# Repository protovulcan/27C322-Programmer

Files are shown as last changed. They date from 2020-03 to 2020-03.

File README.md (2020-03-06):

# ST27C322 EPROM Programmer

Build Rev-1a
  
This schematic is for an EPROM programmer that I put together to allow me to build a switchable Amiga Kickstart.  The plan is to put DiagROM and Kickstarts v1.3, v2.4, and v3.1.1 on a single EPROM. It uses a boost converter to generate the programming voltage _VPP_ so it can be run from USB only. It uses [MCP23017](./docs/MCP23017-datasheet.pdf) IO extenders to generate enough Address and Data lines. The Data lines are driven by the io extender at ```0x20``` while the high data lines are driven by the io extender at ```0x24```.

The current state of this board is alpha. The drill holes for the socket are too small and there are things that need to be properly tested.

The intention with the firmware is to make it handle intel hex via terminal with an ```PASSED``` or:

>
> ERR @ b###########: 0x#### != 0x####
>

# Pinout 

| Arduino | Connected |
|-|-|
| D5 | Address 0 |
| D6 | Address 1 |
| D7 | Address 2 |
| D8 | Address 3 |
| D9 | Address 4 |
| D10 | Programmer Enable - turns on boost converter |
| A0 | INTB on Address io extender |
| A1 | INTA on Address io extender |
| A2 | INTB on Data io extender |
| A3 | INTA on Data io extender |
| A4 | SDA of I2C bus |
| A5 | SDC of I2C bus |
| A6 | RESET of io extender |
| A7 | ENABLE for EEPROM |

# Schematic 

The following schematic was made with KiCAD 5.1.5.  It is currently inadequtely tested.

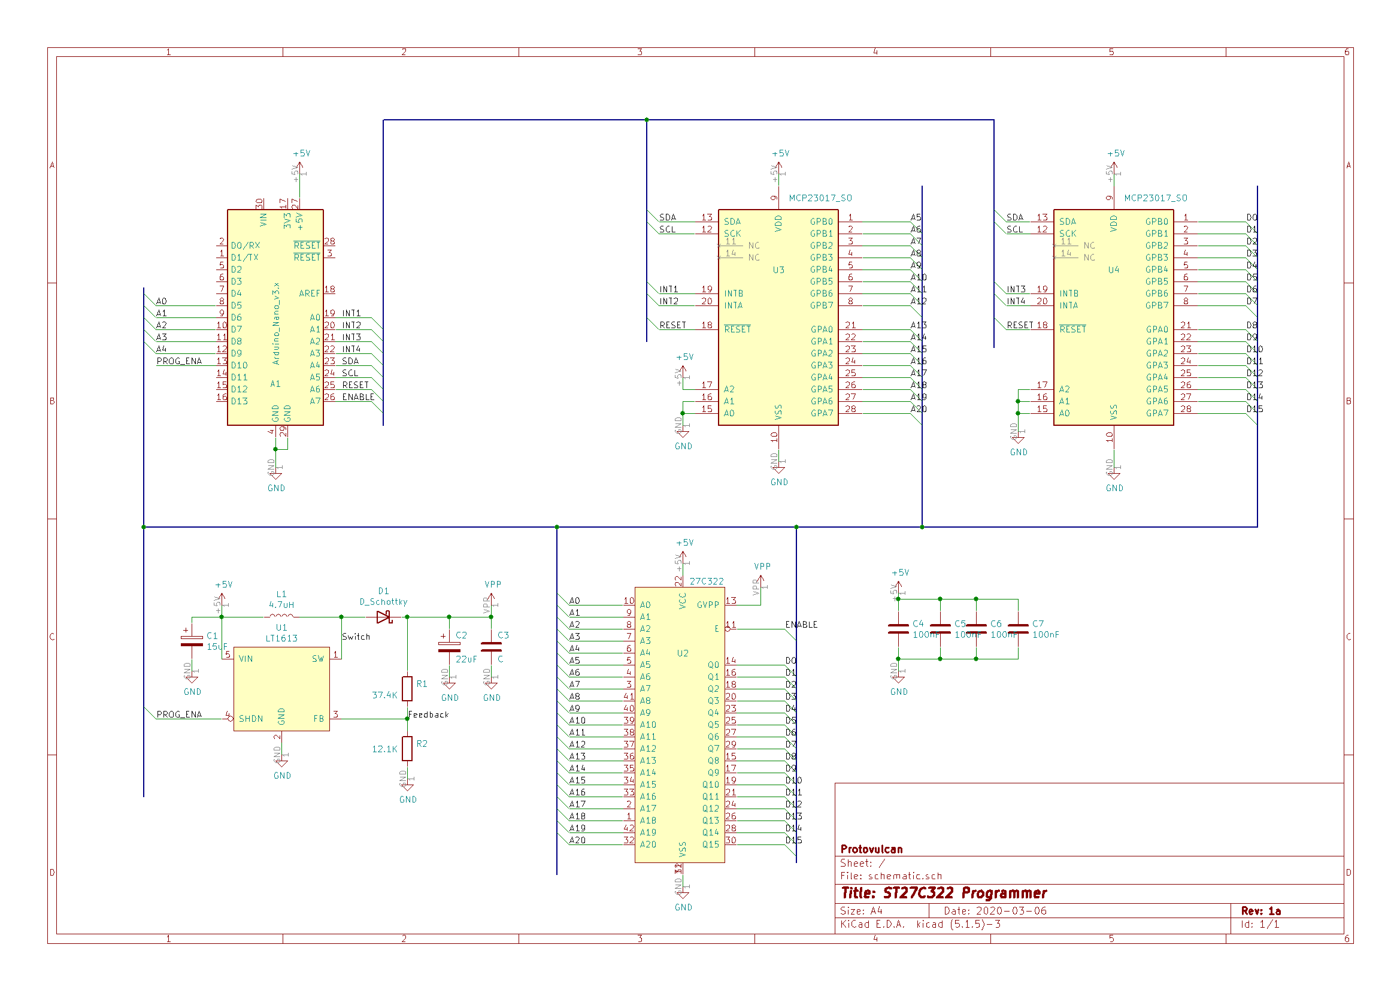
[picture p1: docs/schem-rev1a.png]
Schematic


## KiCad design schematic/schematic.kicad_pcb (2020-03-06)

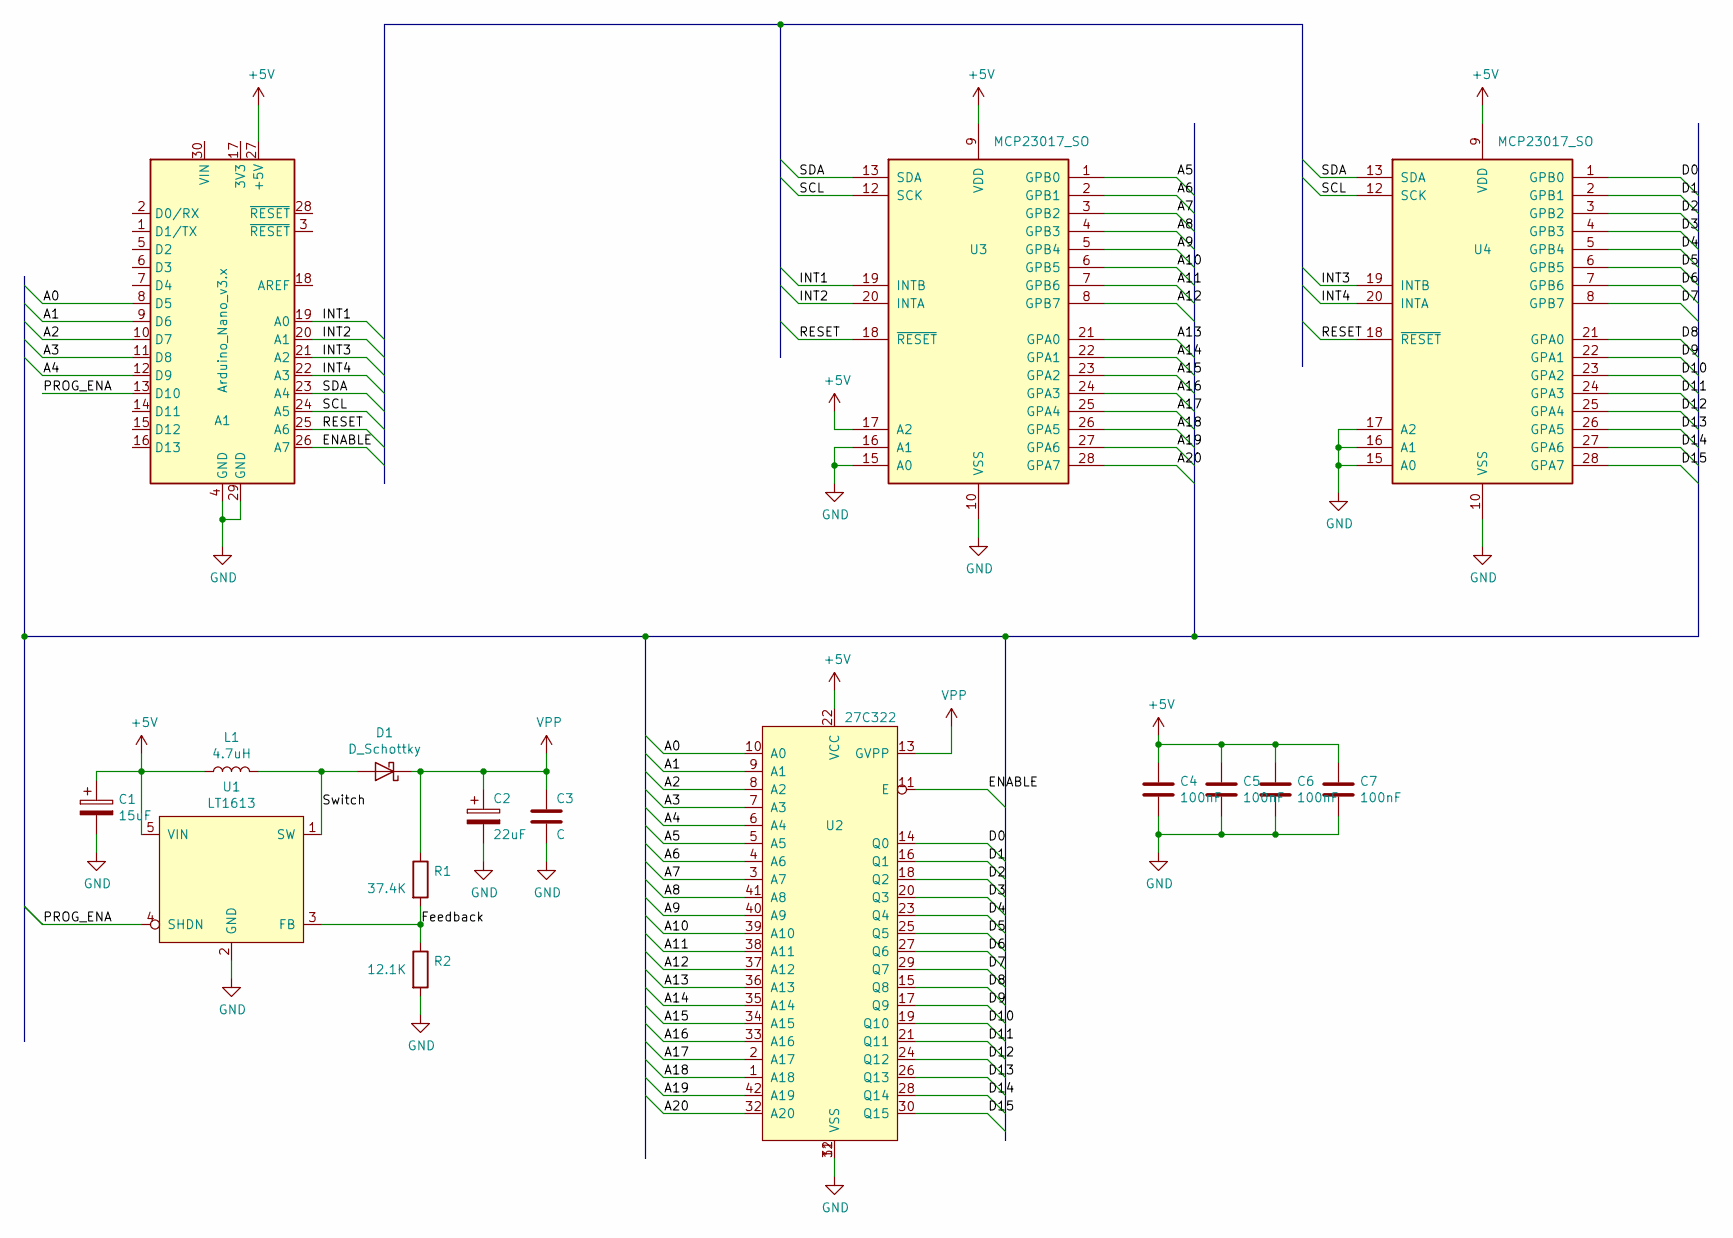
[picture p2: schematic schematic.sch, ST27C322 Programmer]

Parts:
A1: Arduino_Nano_v3.x; Arduino_Nano
C1: 15uF; C_Elec_8x6.2
C2: 22uF; C_Elec_8x6.2
C3: C; C_1210_3225Metric
C4, C5, C6, C7: 100nF; R_1206_3216Metric
D1: D_Schottky; R_1206_3216Metric
L1: 4.7uH; L_10.4x10.4_H4.8
R1: 37.4K; R_1206_3216Metric
R2: 12.1K; R_1206_3216Metric
U1: LT1613; SOT-23-5_HandSoldering
U2: 27C322; DIP-42_W15.24mm_Socket_LongPads
U3, U4: MCP23017_SO; SOIC-28W_7.5x17.9mm_P1.27mm

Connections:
+5V: A1.27 (+5V), C1.1, C4.1, C5.1, C6.1, C7.1, L1.1, U1.5 (VIN), U2.22 (VCC), U3.9 (VDD), U3.17 (A2), U4.9 (VDD)
/A0: A1.8 (D5), U2.10 (A0)
/A1: A1.9 (D6), U2.9 (A1)
/A2: A1.10 (D7), U2.8 (A2)
/A3: A1.11 (D8), U2.7 (A3)
/A4: A1.12 (D9), U2.6 (A4)
/A5: U2.5 (A5), U3.1 (GPB0)
/A6: U2.4 (A6), U3.2 (GPB1)
/A7: U2.3 (A7), U3.3 (GPB2)
/A8: U2.41 (A8), U3.4 (GPB3)
/A9: U2.40 (A9), U3.5 (GPB4)
/A10: U2.39 (A10), U3.6 (GPB5)
/A11: U2.38 (A11), U3.7 (GPB6)
/A12: U2.37 (A12), U3.8 (GPB7)
/A13: U2.36 (A13), U3.21 (GPA0)
/A14: U2.35 (A14), U3.22 (GPA1)
/A15: U2.34 (A15), U3.23 (GPA2)
/A16: U2.33 (A16), U3.24 (GPA3)
/A17: U2.2 (A17), U3.25 (GPA4)
/A18: U2.1 (A18), U3.26 (GPA5)
/A19: U2.42 (A19), U3.27 (GPA6)
/A20: U2.32 (A20), U3.28 (GPA7)
/D0: U2.14 (Q0), U4.1 (GPB0)
/D1: U2.16 (Q1), U4.2 (GPB1)
/D2: U2.18 (Q2), U4.3 (GPB2)
/D3: U2.20 (Q3), U4.4 (GPB3)
/D4: U2.23 (Q4), U4.5 (GPB4)
/D5: U2.25 (Q5), U4.6 (GPB5)
/D6: U2.27 (Q6), U4.7 (GPB6)
/D7: U2.29 (Q7), U4.8 (GPB7)
/D8: U2.15 (Q8), U4.21 (GPA0)
/D9: U2.17 (Q9), U4.22 (GPA1)
/D10: U2.19 (Q10), U4.23 (GPA2)
/D11: U2.21 (Q11), U4.24 (GPA3)
/D12: U2.24 (Q12), U4.25 (GPA4)
/D13: U2.26 (Q13), U4.26 (GPA5)
/D14: U2.28 (Q14), U4.27 (GPA6)
/D15: U2.30 (Q15), U4.28 (GPA7)
/ENABLE: A1.26 (A7), U2.11 (E)
/Feedback: R1.2, R2.1, U1.3 (FB)
/INT1: A1.19 (A0), U3.19 (INTB)
/INT2: A1.20 (A1), U3.20 (INTA)
/INT3: A1.21 (A2), U4.19 (INTB)
/INT4: A1.22 (A3), U4.20 (INTA)
/PROG_ENA: A1.13 (D10), U1.4 (SHDN)
/RESET: A1.25 (A6), U3.18 (~RESET~), U4.18 (~RESET~)
/SCL: A1.24 (A5), U3.12 (SCK), U4.12 (SCK)
/SDA: A1.23 (A4), U3.13 (SDA), U4.13 (SDA)
/Switch: D1.2 (A), L1.2, U1.1 (SW)
GND: A1.4 (GND), A1.29 (GND), C1.2, C2.2, C3.2, C4.2, C5.2, C6.2, C7.2, R2.2, U1.2 (GND), U2.12 (VSS), U2.31 (VSS), U3.10 (VSS), U3.15 (A0), U3.16 (A1), U4.10 (VSS), U4.15 (A0), U4.16 (A1), U4.17 (A2)
VPP: C2.1, C3.1, D1.1 (K), R1.1, U2.13 (GVPP)

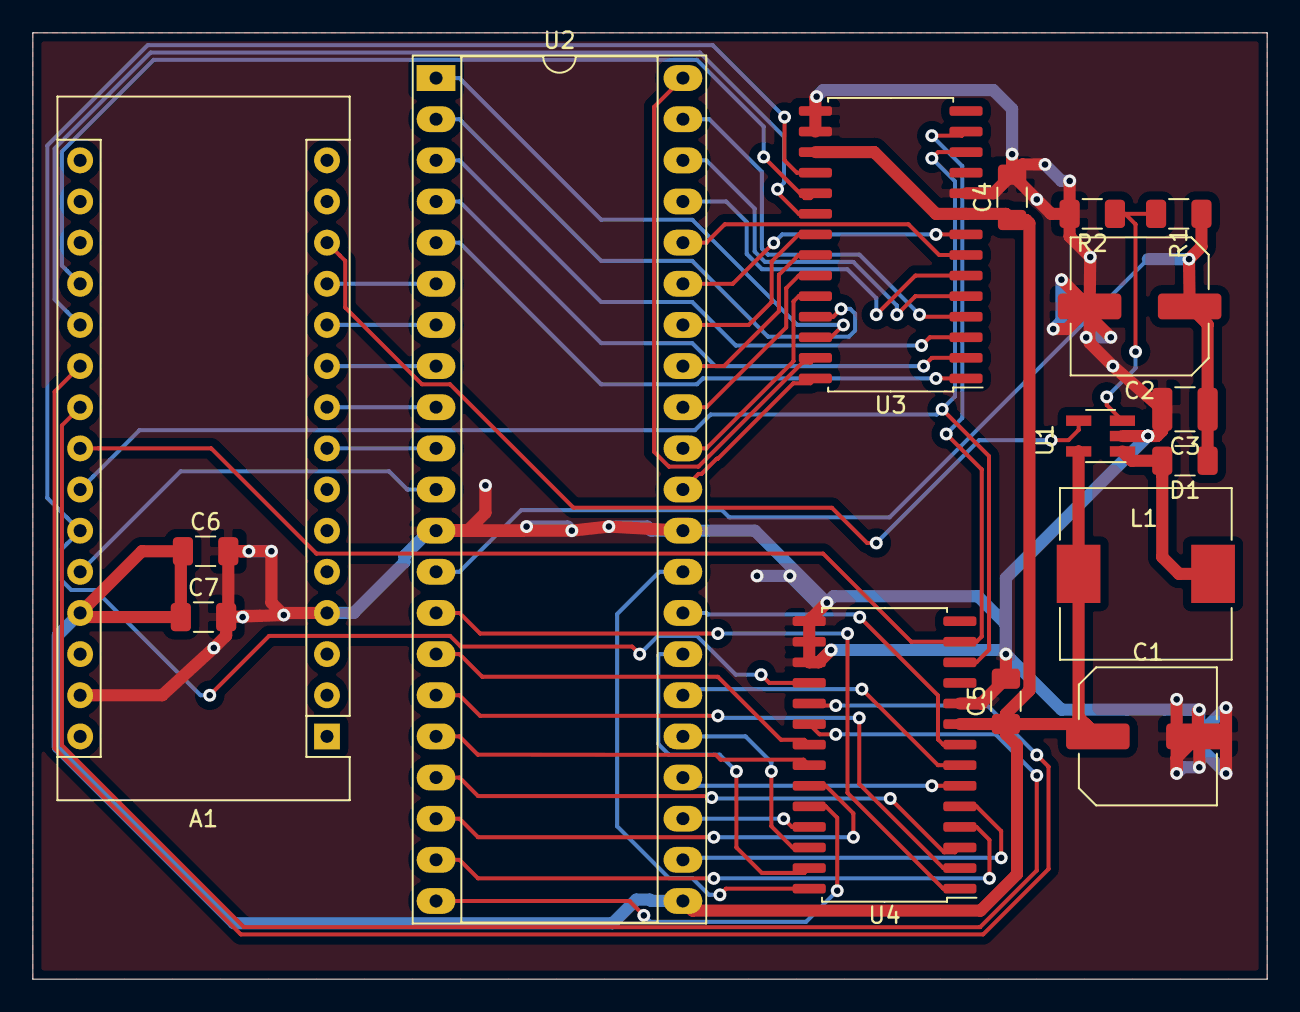
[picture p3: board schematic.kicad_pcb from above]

Board: 2 copper layers, 76.2 x 58.4 mm, 16 parts (0 on the bottom side), 51 nets.

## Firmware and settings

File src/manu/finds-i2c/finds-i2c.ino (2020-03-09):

#include <Wire.h>


#define ADDR0 5 // D5
#define ADDR1 6 // D6
#define ADDR2 7 // D7
#define ADDR3 8 // D8
#define ADDR4 9 // D9
#define ENABLE 10 // D10
#define INT1 14 // A0
#define INT2 15 // A1
#define INT3 16 // A2
#define INT4 17 // A3
#define RESET  12 // A6 - fuck bodge wire time
#define ENABLE 11 // A7 - fuck bodge wire time


void setup()
{
    pinMode(RESET, OUTPUT);
    pinMode(ENABLE, OUTPUT);
    pinMode(ADDR0, OUTPUT);
    pinMode(ADDR1, OUTPUT);
    pinMode(ADDR2, OUTPUT);
    pinMode(ADDR3, OUTPUT);
    pinMode(ADDR4, OUTPUT);
    pinMode(INT1, INPUT);
    pinMode(INT2, INPUT);
    pinMode(INT3, INPUT);
    pinMode(INT4, INPUT);
    Wire.begin();
    delay(100);
    Serial.begin(115200);
    Serial.println('I2C Scan');
    reset();
    delay(100);
}

void reset() 
{
    digitalWrite(RESET,0);
    delay(50);
    digitalWrite(RESET,1);
}

void phex(byte address)
{
    if (address < 16) Serial.print("0");
    Serial.print(address, HEX);
}

void loop()
{
    byte error, address;

    for (address = 1; address < 127; address++)
    {
        Wire.beginTransmission(address);
        error = Wire.endTransmission();

        phex(address);

        Serial.print(" ");
        Serial.println(error, HEX);
    }

    delay(5000); // wait 5 seconds for next scan
}

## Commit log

2020-03-06 Progress with the building and testing
    [schematic.kicad_pcb, schematic.sch]
2020-03-09 Test code to work out if I2C is doing what it should
